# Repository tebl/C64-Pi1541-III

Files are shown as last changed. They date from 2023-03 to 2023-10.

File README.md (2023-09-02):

# C64 Pi1541-III
Well... if you're here, then that new and shiny SD2IEC for your Commodore 64 wasn't cycle-exact enough for you? Sure, there are great FPGA-based solutions available that can be purchased at a premium pricepoint. For the rest of us who are either on a tight budget - or - simply want something that they can build at home, then the excellent Pi1541-software written by Steve White may very well be the solution you've been looking for. With a Raspberry Pi 3 at its core, it is able to provide cycle-exact disk drive emulation with many improvements over the drive you had in your youth!

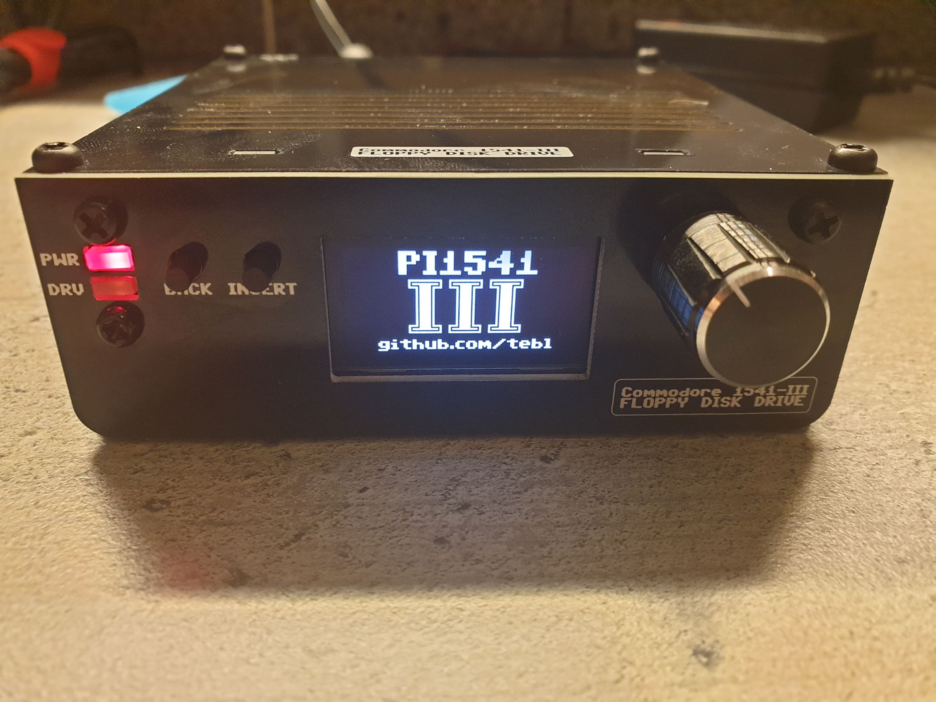
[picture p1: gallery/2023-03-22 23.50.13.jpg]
Pi1541-III


A Pi1541 can be constructed in many ways, but even though you can easily build one without the help of a PCB such as the ones provided by this project - I've found it a lot easier to make them work when you have a PCB available. I've released the design files for a more traditional Raspberry Pi-hat if you would rather build one of those, these can be found in my old repository at [C64-Pi1541-Module](https://github.com/tebl/C64-Pi1541-Module). A slightly different take on the device can also be found at [C64-Pi1541-II](https://github.com/tebl/C64-Pi1541-II) as it was made to resemble a slightly smaller stack of floppy disks.

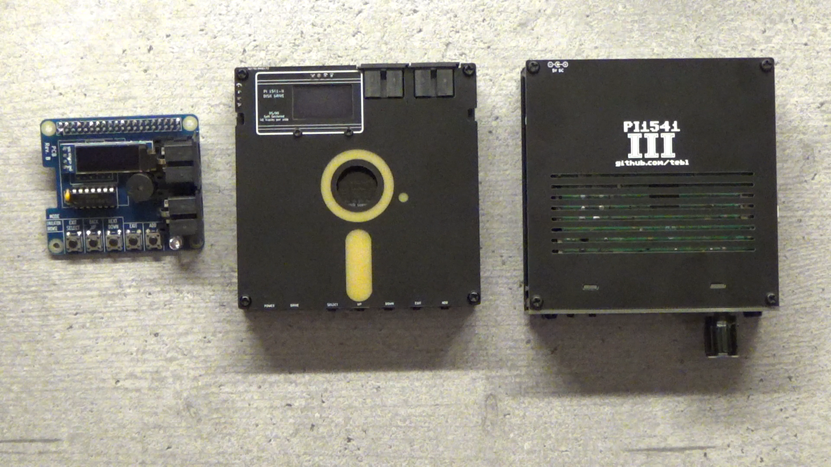
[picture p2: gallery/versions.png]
Three versions of Pi1541


With this third version I've instead attempted to make one that's more akin to a modern device, incorporating a 1.3" OLED on the front as being controlled via the use of a rotary encoder. While the design aesthetic makes it slightly harder to build than your standard Pi1541, I believe that it more than makes up for it.

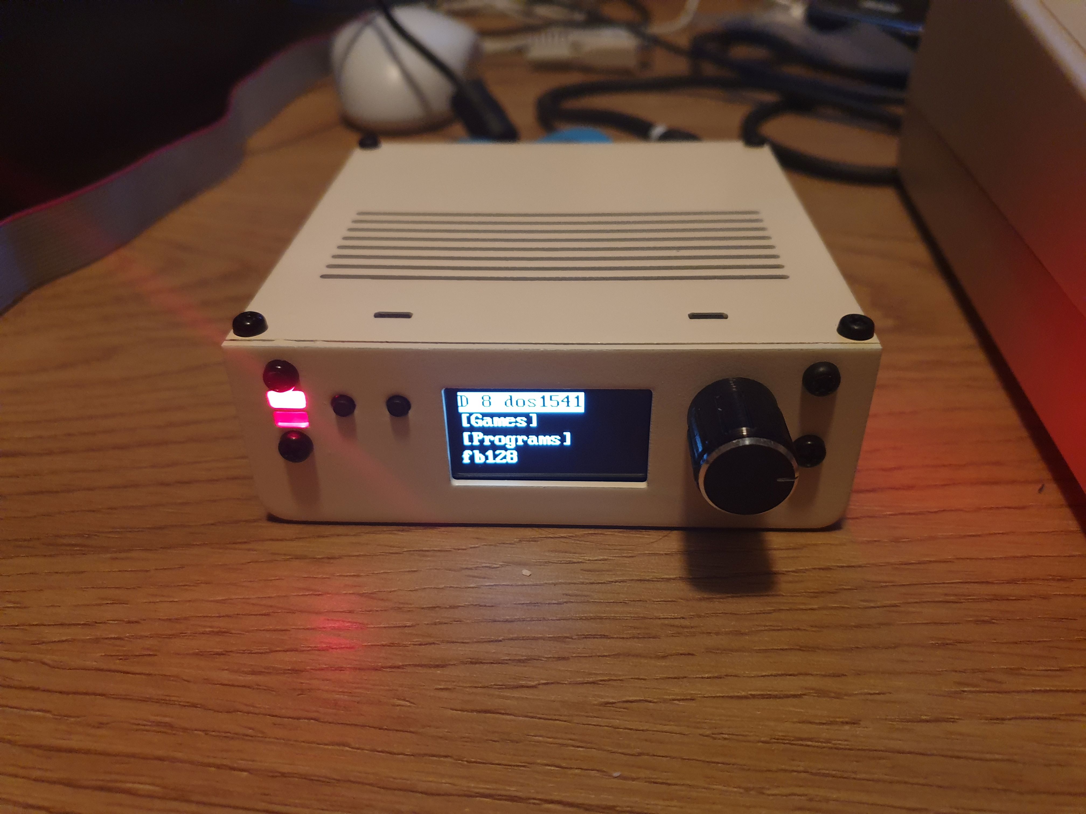
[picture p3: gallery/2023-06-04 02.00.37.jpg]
Pi1541-III (Painted)


- [1> Modules](#1-modules)
- [2> Documentation](#2-documentation)
  - [2.1> Resources](#21-resources)
- [3> Acknowledgements](#3-acknowledgements)

## 1> Modules
A complete Pi1541 requires no less than five PCBs in order to be built as pictured, for a somewhat simpler build you may skip the bottom faceplate though that also serves a purpose and it wouldn't entirely be complete without it. See below for a side view of how the device is put together, there is a top and bottom faceplate as well as another faceplate on the front. The PCB at the center will in the documentation be referred to as the *Pi1541-III Module* while the smaller one towards the front will be referred to as the *panel*.

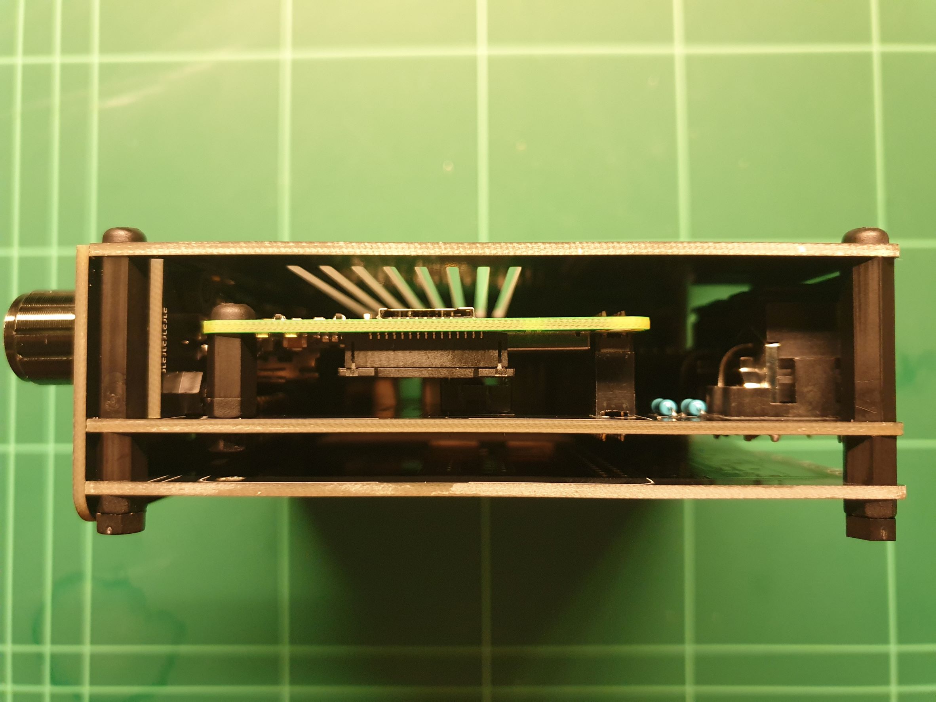
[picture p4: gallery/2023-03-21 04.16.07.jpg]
Pi1541-III side view


In order to keep things in an order that's mostly organized, I've had to separate out information such as the *BOM* that goes into the build for the modules they belong to - hopefully making things easier if I ever start doing alternate versions with other components. See further below for [documentation](#2-documentation) on how to assemble one, set it up as well as anything else that you might need to know.

| Module | Required | Description | Documentation | Order |
| --- | --- | --- | --- | --- |
| [C64 Pi1541-III Module](https://github.com/tebl/C64-Pi1541-III/tree/main/C64%20Pi1541-III%20Module) | Yes | Main module |  [BOM](https://github.com/tebl/C64-Pi1541-III/tree/main/C64%20Pi1541-III%20Module/README.md#3-bom) | [PCBWay](https://www.pcbway.com/project/shareproject/C64_Pi1541_III_Module_629bebca.html)
| [C64 Pi1541-III Module Panel](https://github.com/tebl/C64-Pi1541-III/tree/main/C64%20Pi1541-III%20Module%20Panel) | Yes | Adds a vertical surface for mounting switches and rotary encoder. |  [BOM](https://github.com/tebl/C64-Pi1541-III/tree/main/C64%20Pi1541-III%20Module%20Panel/README.md#3-bom) | [PCBWay](https://www.pcbway.com/project/shareproject/C64_Pi1541_III_Panel_39049bfb.html)
| [C64 Pi1541-III Faceplate (FB1)](https://github.com/tebl/C64-Pi1541-III/tree/main/faceplates/C64%20Pi1541-III%20Module%20FB1) | Yes | Top faceplate, provides mechanical support for front panel. | | [PCBWay](https://www.pcbway.com/project/shareproject/C64_Pi1541_III_Faceplate_FB1_d125443d.html)
| [C64 Pi1541-III Faceplate (FB2)](https://github.com/tebl/C64-Pi1541-III/tree/main/faceplates/C64%20Pi1541-III%20Module%20FB2) | Recommended | Bottom faceplate, adds a layer of security so that you don't accidentally short out the device on something placed under it. | | [PCBWay](https://www.pcbway.com/project/shareproject/C64_Pi1541_III_Faceplate_FB2_912f9cbb.html)
| [C64 Pi1541-III Faceplate (FP1)](https://github.com/tebl/C64-Pi1541-III/tree/main/faceplates/C64%20Pi1541-III%20Module%20FP1) | Recommended | Front faceplate, this is mainly here to make things look nice. | | [PCBWay](https://www.pcbway.com/project/shareproject/C64_Pi1541_III_Faceplate_FP1_228805ce.html)

# 2> Documentation
There are many things that need to be said in order to successfully put a working Pi1541 together, and while the information may seem pedantic and at that times simplified for veterans at building electronical devices - I'm just an amateur and so I try to include everything that would have been needed when I first started building things such as this.

If you've just come across this page and have been wondering exactly what components you need to order in order to build the Pi1541, then I suggest that you start on the [modules](#1-modules)-section - each of modules listed are PCBs that you will most likely want. In the same list there is a link to the BOM belonging to that specific module, you need to order the components for each of them.

This repository does not include Gerber-files, you either need to generate those from the KiCAD source files found in this repository - the easiest way to order them via [PCBWay](https://www.pcbway.com/project/shareproject/?tag=Pi1541-III). Note that for the faceplates specifically, you may want to pay a little bit extra to avoid having the order number printed on it - or specifically tell them to put it on the back.

For everything else, I can only hope that one of the following documents will provide you with the answers that you need:
- [Assembling one](https://github.com/tebl/C64-Pi1541-III/blob/main/documentation/assembling_one.md)
- [Setting it up](https://github.com/tebl/C64-Pi1541-III/blob/main/documentation/setting_it_up.md)
- [Troubleshooting](https://github.com/tebl/C64-Pi1541-III/blob/main/documentation/troubleshooting.md)

## 2.1> Resources
- [Pi1541 Homepage](https://cbm-pi1541.firebaseapp.com/)
- [fat32format](http://ridgecrop.co.uk/index.htm?guiformat.htm)
- [Shared PCBWay projects for Pi1541-III](https://www.pcbway.com/project/shareproject/?tag=Pi1541-III)

# 3> Acknowledgements
Everything comes from something, in particular when it comes to most of my electronics projects. I mainly build things I would like to own, often doing a respin to fit my own particular style and preferences with most of the hardest parts of the designs already provided by people more knowledgable than I.

The Pi1541-III would not exist if it were not for the work of Steve White, creator of the [Pi1541](https://cbm-pi1541.firebaseapp.com/)-software that makes this jumble of PCBs come alive!

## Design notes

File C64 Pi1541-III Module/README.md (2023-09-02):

# Pi1541-III Module
This is the main PCB and will hold most of the active components in the device, but note that it is designed to be used with [Pi1541-III Module Panel](https://github.com/tebl/C64-Pi1541-III/tree/main/C64%20Pi1541-III%20Module%20Panel) and has one listed in the [BOM](#3-bom). Note that the mentioned panel also has its own separate [BOM](https://github.com/tebl/C64-Pi1541-III/tree/main/C64%20Pi1541-III%20Module%20Panel/README.md#3-bom), so keep that in mind while ordering components.

- [1> Build instructions](#1-build-instructions)
- [2> Schematic](#2-schematic)
- [3> BOM](#3-bom)

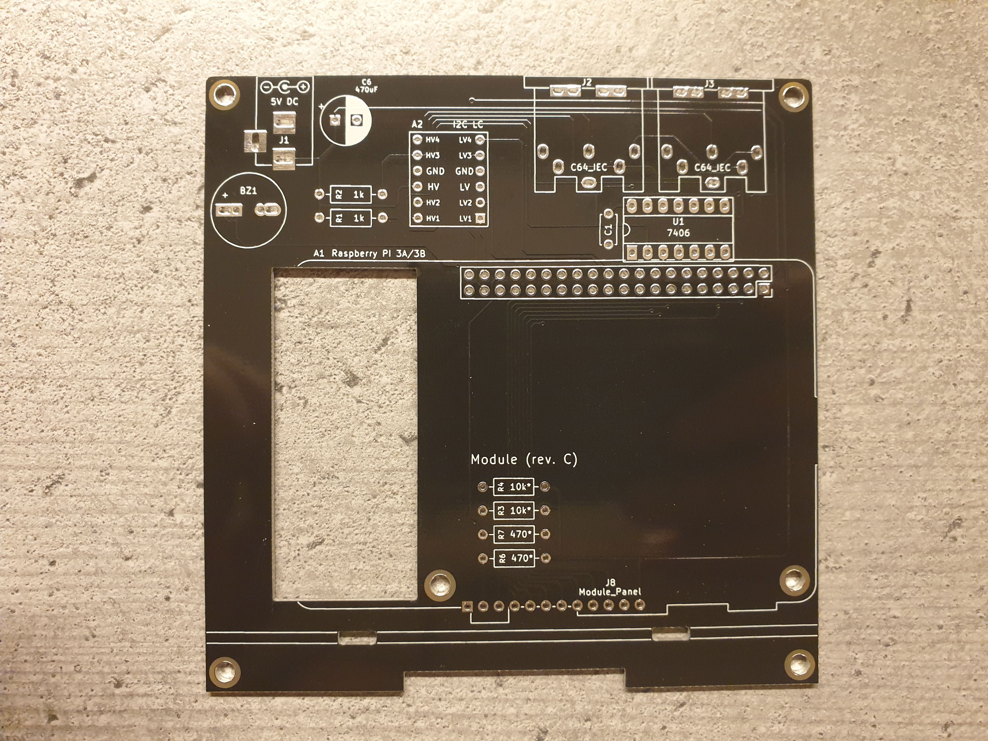
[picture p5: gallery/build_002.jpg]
Current PCB


# 1> Build instructions
Assembling this module is covered as part of the overall documentation, as linked below. Note that *BOM* is supplied per module, the one belonging to this module in particular is included as part of this document (click [here](#3-bom) to go there).

- [Assembling one](https://github.com/tebl/C64-Pi1541-III/blob/main/documentation/assembling_one.md)

# 2> Schematic
The supplied KiCad files should be sufficient as both a schematic and as a  starting point for ordering PCBs (basically you could just zip the contents of the export folder and upload that on a fabrication site), the schematic is also available in [PDF-format](https://github.com/tebl/C64-Pi1541-III/tree/main/documentation/schematic) and this is what you'll need to print and work your way through this things don't work as expected after assembly.

# 3> BOM
Most parts should be easy to get a hold of from your favourite local electronic component shop, but given that I don't have access to such shops where I live so everything was based on whatever I could get cheapest from eBay/AliExpress (free shipping, but plan on waiting 3-4 weeks for delivery). Components in parenthesis can be considered optional for features beyond the more basic functionality, but where's the fun in that? You deserve the complete package.

| Reference | Item | Count | Order  |
| --- | --- | ----- | --- |
| Module PCB | PCB specific to this project | 1 | [See modules](https://github.com/tebl/C64-Pi1541-III/blob/main/README.md#1-modules)
| Faceplate (FB1) PCB | Top faceplate | 1 | [See modules](https://github.com/tebl/C64-Pi1541-III/blob/main/README.md#1-modules)
| Faceplate (FB2) PCB | Bottom faceplate | (1)| [See modules](https://github.com/tebl/C64-Pi1541-III/blob/main/README.md#1-modules)
| A1 | 2x20 pin female header | 1 |
| | Raspberry Pi version 3B,3B+ or 3A+ | 1 |
| A2 *1 | 4ch I2C level converter module | 1 |
| BZ1 | Passive buzzer (pin spacing from 3.81 to 7mm will work) | (1) |
| C1 | 100nF ceramic capacitor (5mm) | 1 |
| C6 | 470uF electrolytic capacitor (8mm x 3.5mm) | 1 |
| J1 | 2.1mm x 5.5mm barrel plug | 1 |
| J2,J3 | Female S-terminal 6-pin DIN PCB |  1 (1)|
| J8 | [Pi1541-III Module Panel](https://github.com/tebl/C64-Pi1541-III/tree/main/C64%20Pi1541-III%20Module%20Panel) (completed unit) | 1 |
| R1,R2 | 1k Ohm resistor | 2 |
| R3,R4 | 10k Ohm resistor | 2 |
| R6,R7 *2 | 470 Ohm resistor | 2 |
| U1 *3 | 7406 (DIP-14) | 1 |
| Mounting *4 | Nylon M3 hex standoffs 6mm (M-F) | 4 |
| Mounting *4 | Nylon M3 hex standoffs 8mm (M-F) | 2 |
| Mounting *5 | Nylon M3 hex standoffs 12mm (M-F) | (4)|
| Mounting *4 | Nylon M3 hex standoffs 20mm (M-F) | 4 |
| Mounting *4 | Nylon M3x6mm nylon screws | 6 |
| Mounting *4 | Nylon M3x6mm nylon nuts | 12 |

1) There are multiple configurations of these being sold, this is usually sold with a blue PCB. When in doubt, compare the sale listing with the one shown in this [image](https://raw.githubusercontent.com/tebl/C64-Pi1541-III/main/gallery/build_006B.jpg).
2) This is the resistor for the LEDs mounted on [Pi1541-III Module Panel](https://github.com/tebl/C64-Pi1541-III/tree/main/C64%20Pi1541-III%20Module%20Panel), the value need to be sized according to the type of LED being used. This value is a somewhat safe choice cheaper coloured LEDs, for anything blue or especially marked as being *bright* - then you need to calculate a proper value for these.
3) There are unfortunately counterfeit 7406-chips being circulated, the ones I've had the most success with has been marked 7406PC though a handful of SN7406 have also been found working. See [troubleshooting](https://github.com/tebl/C64-Pi1541-III/blob/main/documentation/troubleshooting.md) for more information.
4) These are used in various places of the project, these are available in the form of kits usually advertised *M3 nylon standoff kit* which should contain most of what you'd need though you should check that they include them in sufficient quantity.
5) These are only needed when *NOT* installing bottom faceplate ([Pi1541-III Faceplate (FB2)](https://github.com/tebl/C64-Pi1541-III/tree/main/faceplates/C64%20Pi1541-III%20Module%20FB2))

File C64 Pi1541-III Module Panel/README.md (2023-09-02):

# Pi1541-III Module Panel
This PCB holds the components for the front panel, it was designed to mount on top of [Pi1541-III Module](https://github.com/tebl/C64-Pi1541-III/tree/main/C64%20Pi1541-III%20Module). This panel has its own BOM, so keep that in mind when ordering components - as you'll be needing parts listed for both of them to build a complete device.

- [1> Build instructions](#1-build-instructions)
- [2> Schematic](#2-schematic)
- [3> BOM](#3-bom)

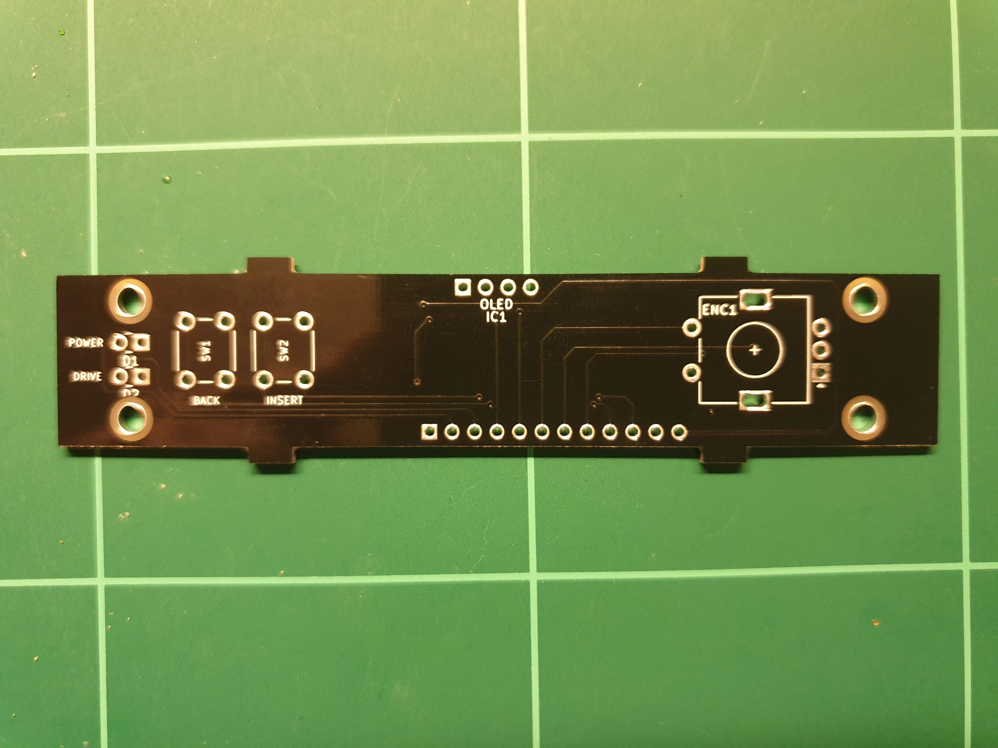
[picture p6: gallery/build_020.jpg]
Current PCB


# 1> Build instructions
Assembling this module is covered as part of the overall documentation, as linked below. Note that *BOM* is supplied per module, the one belonging to this module in particular is included as part of this document (click [here](#3-bom) to go there).
- [Assembling one](https://github.com/tebl/C64-Pi1541-III/blob/main/documentation/assembling_one.md)

# 2> Schematic
The supplied KiCad files should be sufficient as both a schematic and as a  starting point for ordering PCBs (basically you could just zip the contents of the export folder and upload that on a fabrication site), the schematic is also available in [PDF-format](https://github.com/tebl/C64-Pi1541-III/tree/main/documentation/schematic) and this is what you'll need to print and work your way through this things don't work as expected after assembly.

# 3> BOM
Most parts should be easy to get a hold of from your favourite local electronic component shop, but given that I don't have access to such shops where I live so everything was based on whatever I could get cheapest from eBay/AliExpress (free shipping, but plan on waiting 3-4 weeks for delivery). Components in parenthesis can be considered optional for features beyond the more basic functionality, but where's the fun in that? You deserve the complete package.

| Reference | Item | Count | Order  |
| --- | --- | ----- | --- |
| Module Panel PCB | PCB specific to this project | 1 | [See modules](https://github.com/tebl/C64-Pi1541-III/blob/main/README.md#1-modules)
| Faceplate (FP1) PCB | Front faceplate | (1)| [See modules](https://github.com/tebl/C64-Pi1541-III/blob/main/README.md#1-modules)
| IC1 *1 | SH1106 I2C OLED 128x64 (1.3") | 1 |
| ENC1 | EC11 rotary encoder, 20mm. Preferably plum handle. | 1 |
| | Suitable knob for rotary encoder, max 20mm in diameter. | (1)|
| D1,D2 | 2x5x7mm rectangular LED, suitably coloured. | 2 |
| J1 | 12-pin right-angle pin header | 1 |
| SW1,SW2 | 6x6mm momentary switch, 10.5mm or taller. | 2 |
| Mounting *2 | Nylon M3 hex standoffs 8mm (M-F) | 4 |
| Mounting *2 | Nylon M3x6mm nylon screws | 4 |
| Mounting *2 | Nylon M3x6mm nylon nuts | 4 |

1) Many of these will be listed for sale as 1.3" ssd1306-based OLED displays, but they actually have the slightly different sh1106-controller. Something to keep in mind when ordering.
2) These are used in various places of the project, these are available in the form of kits usually advertised *M3 nylon standoff kit* which should contain most of what you'd need though you should check that they include them in sufficient quantity.

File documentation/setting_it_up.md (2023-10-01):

# 1> Setting it up
This part of the documentation takes care of setting up your Pi1541-III, taking care of everything needed to enjoy using it after the hardware has previously been [assembled](https://github.com/tebl/C64-Pi1541-III/blob/main/documentation/assembling_one.md). While most of this information would be relevant to any build of a pi1541, this guide will cover the relevant differences for the Pi1541-III in particular - type of display, use of rotary encoder, that kind of *thing*.

- 1> Setting it up
- [2> Video](#2-video)
- [3> Written instructions](#3-written-instructions)
  - [3.1> Preparing SD-card](#31-preparing-sd-card)
  - [3.2> Copying necessary files](#32-copying-necessary-files)
  - [3.3> Edit configuration](#33-edit-configuration)
  - [3.4> Testing it out](#34-testing-it-out)

## 2> Video
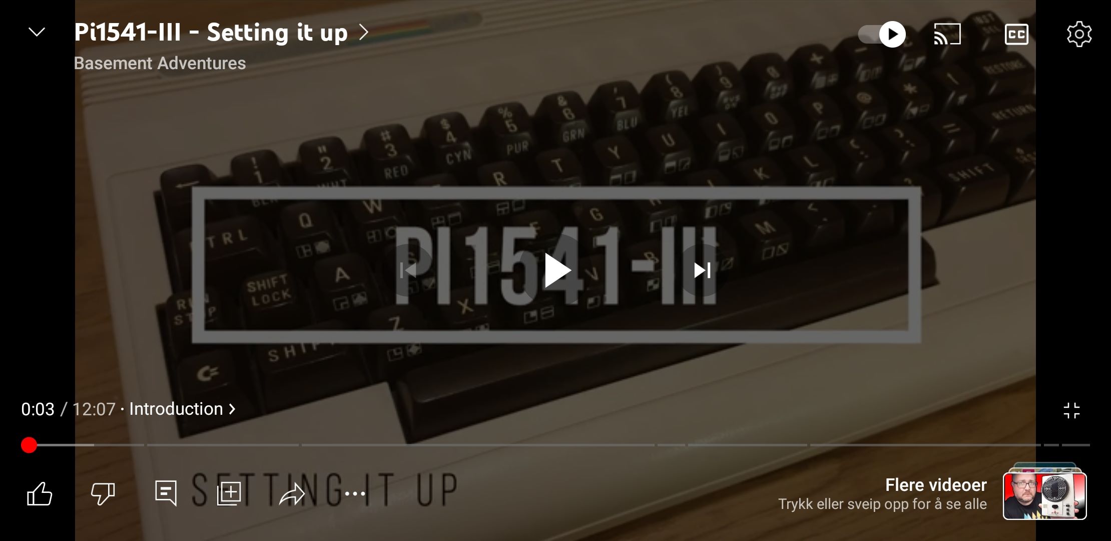
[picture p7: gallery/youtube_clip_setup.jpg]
YouTube image (https://youtu.be/a_sJkwbnSls)


## 3> Written instructions
As a video for this exists, I'll try to keep this brief by mainly attempt to supplement the contents of it - if you hate having to pause a video to read a piece of text, then this is the section you wanted. The following sections have been provided, feel free to skip ahead if you feel confident in your own abilities - and - promise to return when you find out that things did not work as expected (or at all).

- [3.1> Preparing SD-card](#31-preparing-sd-card)
- [3.2> Copying necessary files](#32-copying-necessary-files)
- [3.3> Edit configuration](#33-edit-configuration)
- [3.4> Testing it out](#34-testing-it-out)
  
### 3.1> Preparing SD-card
In order to prepare an SD-card, you will first need to have an SD-card and an SD-card reader. The speed isn't all that much of an issue, a *reasonably* priced slower cards will more than likely work - you'll simply end up waiting longer when adding your entire collection of disk files to it. One thing that is **important**, is that you bought a "*reasonably* priced card", if it seemed like too much of a good deal when ordering it online - then it's practically guaranteed to have been produced with a non-existing capacity. Throw them away and get a refund, any data added beyond a certain limit will simply overwrite previous data and you'll have a cycle of corruption that will in no way function. 

The card that you ended up purchasing from a good local electronics vendor (with or without extra steps due to fake products bought), won't have a file system that a Raspberry Pi can boot from - most cards from 16GB and upwards will have been formatted for you with the *exFAT* file system instead. We need it to have *FAT32*, something that most operating systems by anyone other than Microsoft should handle fine (just make sure that you format the correct drive).

If you were to use any version of Microsoft Windows, then all hope is definitely not lost - we just require some third-party tools to do that. There are a few good ones out there, but there's a LOT of spyware, bloatware and straight up ransomware masquerading as such tools - so use one that you're familiar with and trust. The one I tend to use is [fat32format](http://ridgecrop.co.uk/index.htm?fat32format.htm) - it might look like something from a couple of centuries ago, but so is the one that came with MS Windows so here we are then. Make sure that you format the correct drive.

### 3.2> Copying necessary files
From the pi1541 homepage at [https://cbm-pi1541.firebaseapp.com/](https://cbm-pi1541.firebaseapp.com/), download the latest binaries for setting up a new SD-card - open up the archive and copy the **contents** of the Pi1541 directory directly to the root of your SD-card.

Download the [Raspberry Pi Foundation](https://github.com/raspberrypi/firmware/archive/1.20180919.zip) archive, opening it up you need to open the first and only folder on it. Within the subsequent subfolder, named **boot**, you'll need to copy the following files to the root of your SD-card:
- bootcode.bin
- fixup.dat
- start.elf

The final piece are the ROM-files from an actual Commodore 1541 disk drive, but we don't need to look for a chip extractor just yet - the files are thankfully already included as part of the [VICE](http://vice-emu.sourceforge.net/windows.html) emulator. Download the first listed Zip-file, it doesn't matter if you're not going to be able to run it on your non-Microsoft operating system - as mentioned, we only needed a few files. Opening up the archive, head into the first and only folder - copy the following files to the root of your SD-card.
- DRIVES\dos1541
- DRIVES\dos1571
- DRIVES\dos1581
- C64\chargen

In order to verify that the Pi1541-III has been built correctly, it is recommended that you also download a copy of [Ghosts'n Goblins Arcade](https://www.n0stalgia.org/common/pages/releases.php?op=showrelease&id=329). Open up the archive and copy the d64-file to the 1541-folder on your SD-card.

### 3.3> Edit configuration
The configuration for the Pi1541 software can be changed by editing *options.txt*, a file that should previously have been copied over to your SD-card. We will however need to make some changes to it, the Pi1541-III has been dedisgned to be used with very specific components and we need to set some options in order to make things work. I won't go into a huge amount of details, but suffice it to say you should use the default configuration and make the changes listed below to it.

The first change is to tell it that we've built it up as an option B device, all of the Pi1541-variants designed by me have been built in this way. We therefore need to uncomment this line, as such:
```
// If you are using the split line hardware option (ie Option B) then you need to specify this option
splitIECLines = 1
```
Given that the Pi1541-III was designed for use with a physical display, we won't be needing some of the HDMI functionality and can deactivate those (ideally making the device work less, generating less heat, in theory at least). This is done by changing the value to a zero as such:
```
// This option displays the IEC bus activity on the bottom of the Pi's screen
GraphIEC = 0
```
The buzzer on the device can be enabled, this generates some audiotory feedback to let you know that the device is currently doing something. It's not designed to make any kind of realistic noises, but at least you know that it is doing something instead of just hanging on a dodgy disk image.
```
SoundOnGPIO = 1
SoundOnGPIODuration = 1000 // Length of buzz in micro seconds
SoundOnGPIOFreq = 1200 // Frequency of buzz in Hz
```
The display type needs to be set correctly, anything else will simply result in garbage or nothing at all showing up on the screen. For the Pi1541-III specifically I designed it with the 1.3" OLED modules in mind, these are often sold as ssd1306 compatible displays though they are obviously not - for that reason we need to specify the actual display chip found on them (*sh1106*)
```
// If you are using a LCD screen then specify it here
//LCDName = ssd1306_128x64
//LCDName = ssd1306_128x32
LCDName = sh1106_128x64
```
Some custom boot images have been provided as part of the Pi1541-III project, as well as needed tools in order to create them. These can be found within this repository at [/software/xbm_convert](https://github.com/tebl/C64-Pi1541-III/tree/main/software/xbm_convert), the "raw"-files must be copied to the root of your SD-card. These are optional and I'm mainly including this information as I wasn't able to find it elsewhere, the last line is uncommented and changed to point to one of the new logos.
```
// change startup logo on oled - 1541ii or 1541classic
//LcdLogoName = 1541ii
//LcdLogoName = 1541classic
LcdLogoName = logo_pi1541.raw
```
The final change needed is to set it up to read the rotary encoder that we'll be using, this is replaces the previous way of navigating menus via switches:
```
//ROTARY:
//
//    Please see dmRotary.h for full implementation details.
//
RotaryEncoderEnable = 1
```

With all of that done, make sure to save your changes and safely eject your SD-card.

### 3.4> Testing it out
Plug in the SD-card, then let's pause for a bit to talk about safe power supply choices - in general the extremely cheap options will be cheap **because** they omit all of the features that would normally keep them from burning your house down! As the plug is quite common and just about anything takes 5v these days, consider a proper PSU an investment that you'll be using for all of your other projects as well.

So where do you get proper ones then? Usually an electronics vendor that is local to you, if you are potentially able to punch them in the face - then they won't sell you dangerous stuff. What you'll be looking for should have a standard "barrel" plug on it, but if only to give you something more specific to look for - the one I'm using is a MeanWell GST25B05-P1J (you may need a different model depending on where you live in the world).

With the SD-card plugged in and power applied to it (without connecting it to your C64), then it should start up and allow you to browse the menus using the rotary encoder. If nothing happens or it doesn't seem to work right, please retrace your steps to make sure that the configuration is correct - you can also check out the [troubleshooting](https://github.com/tebl/C64-Pi1541-III/blob/main/documentation/troubleshooting.md) section.

Hooking it up to the C64 you may notice that upon starting up, the display may go blank once the boot logo has been shown - this is the default behaviour when a C64 is connected, but have not been powered on. Turning on the C64 you should be able to browse the menu again, navigate into the 1541 folder and look for that copy of [Ghosts'n Goblins Arcade](https://www.n0stalgia.org/common/pages/releases.php?op=showrelease&id=329) that you copied over earlier, click the rotary encoder to have the Pi1541 start emulating a disk drive with that specific disk inserted.

First ensure that you are able to list the disk contents:
```
LOAD "$",8
LIST
```
If that immediately failed with an error without seeing the Pi1541 activity lights lit up, I would usually suspect a quality issue with the i2c level converter module (in my experience, 2 out of 10 are usually faulty). To rule out the C64, either try connecting a real Commodore 1541 disk drive or alternatively a different C64.

If that looked like it worked, then let's just continue along our merry way and start loading up that game:
```
LOAD "*",8,1
RUN
```
With a fully working Pi1541-III you should be able to load the game all the way via an initially loading menu in between, in particular you should look for corruptions on the image that loads at first (usually pointing to a fake 7406 chip). If it hangs during loading, you may have some other issue -usually solved by using a suitable quality PSU for the Raspberry Pi. Check out [troubleshooting](https://github.com/tebl/C64-Pi1541-III/blob/main/documentation/troubleshooting.md) if you're still stuck at this point.

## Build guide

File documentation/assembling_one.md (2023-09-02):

# 1> Assembling one
Assembling a Pi1541-III from scratch can seem a bit intimidating at first, or not intimidating enough depending on how you look at it. There are quite a lot of things that need to be put together in ways that don't have a huge tolerance for error, that's not to say that it is hard - all that's required is simply to take your time with it. It's more akin to a 3d-puzzle than a standard flat piece of PCB.

- 1> Assembling one
- [2> Video](#2-video)
- [3> Written instructions](#3-written-instructions)

## 2> Video
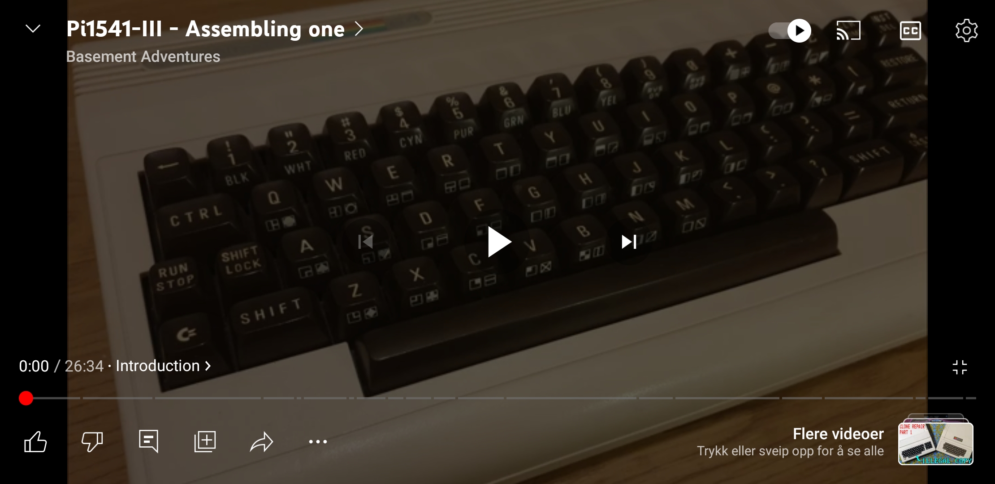
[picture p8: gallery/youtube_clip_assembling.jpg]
YouTube image (https://youtu.be/azvZLPPi7Ts)


## 3> Written instructions
Unfortunately the written instructions don't seem to exist yet.

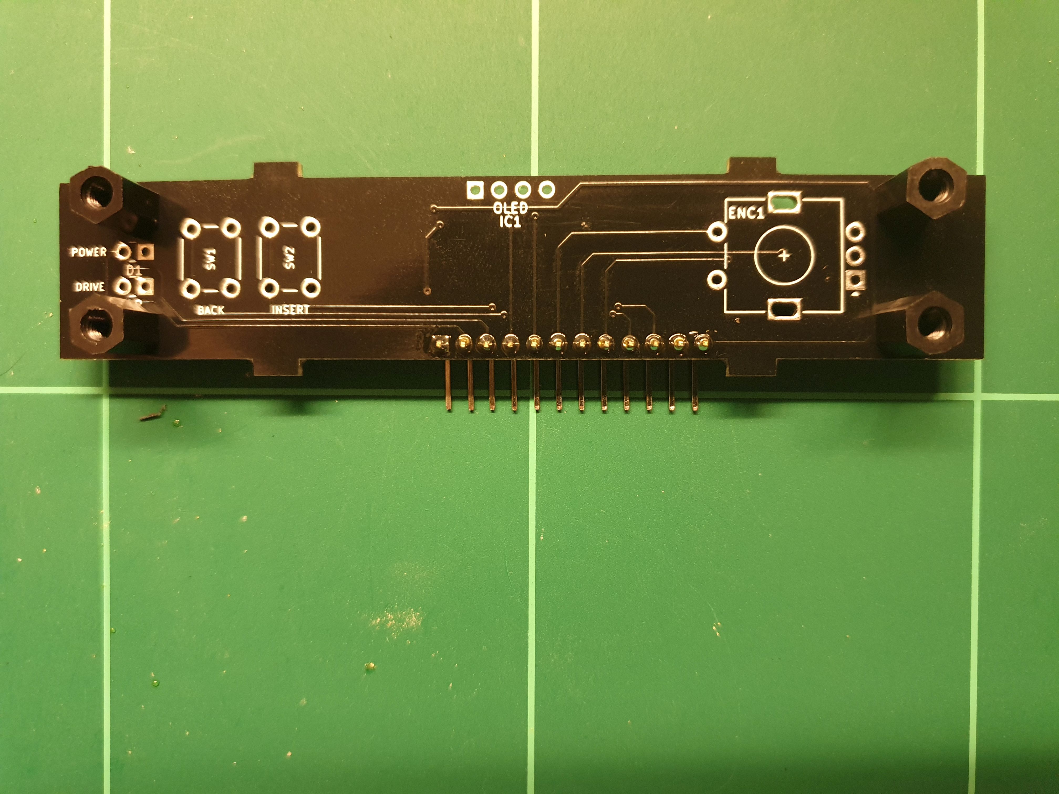
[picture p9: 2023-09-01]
gallery/build_024.jpg

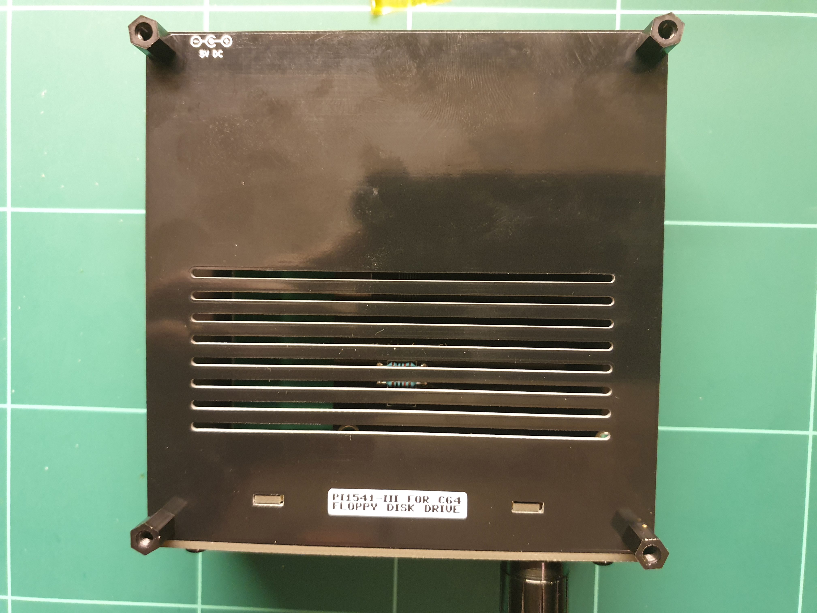
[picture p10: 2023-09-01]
gallery/build_032.jpg

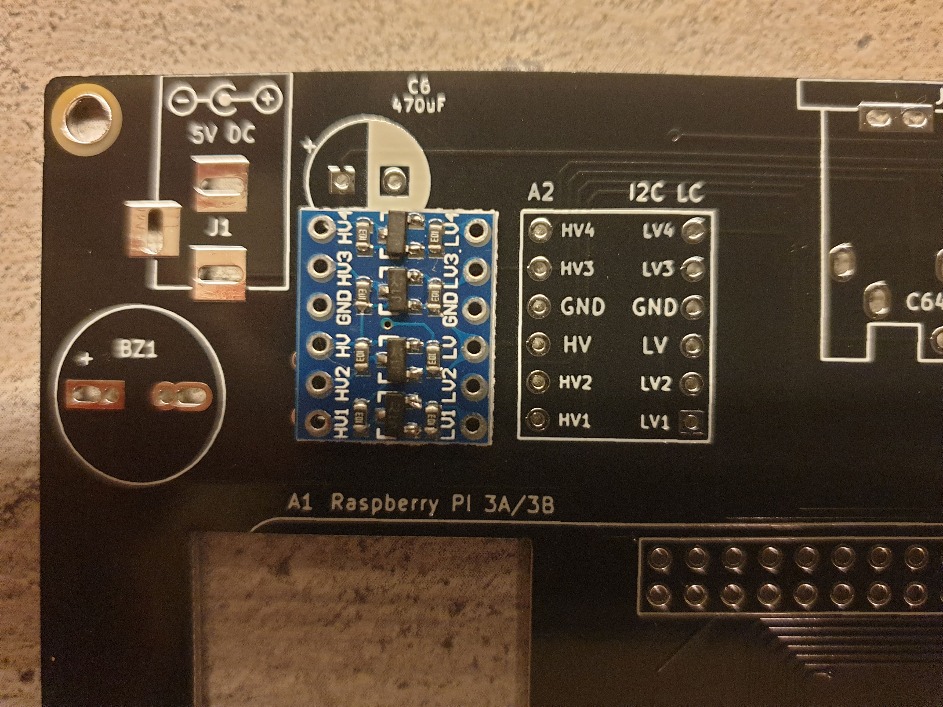
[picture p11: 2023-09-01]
gallery/build_006B.jpg

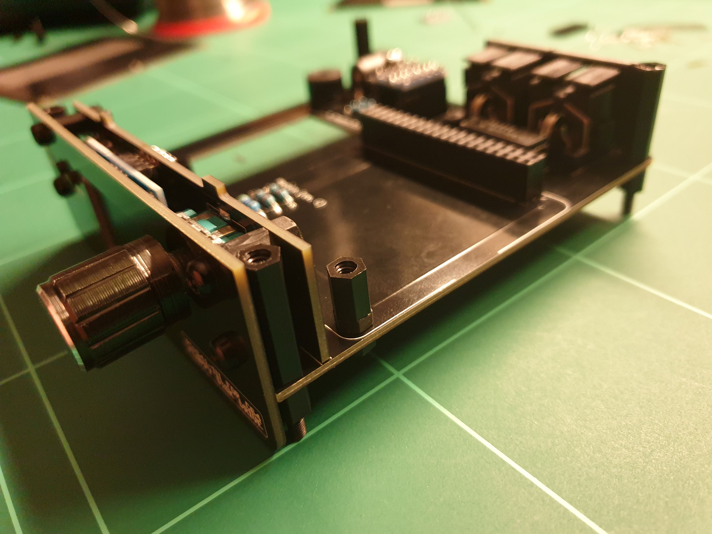
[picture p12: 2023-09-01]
gallery/build_030.jpg

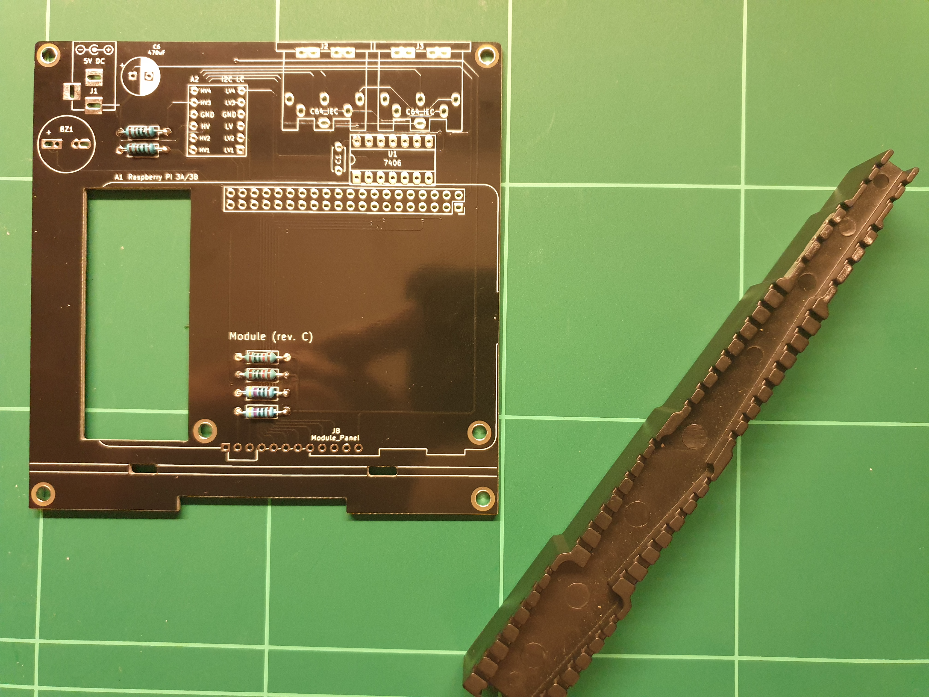
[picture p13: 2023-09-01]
gallery/build_003.jpg

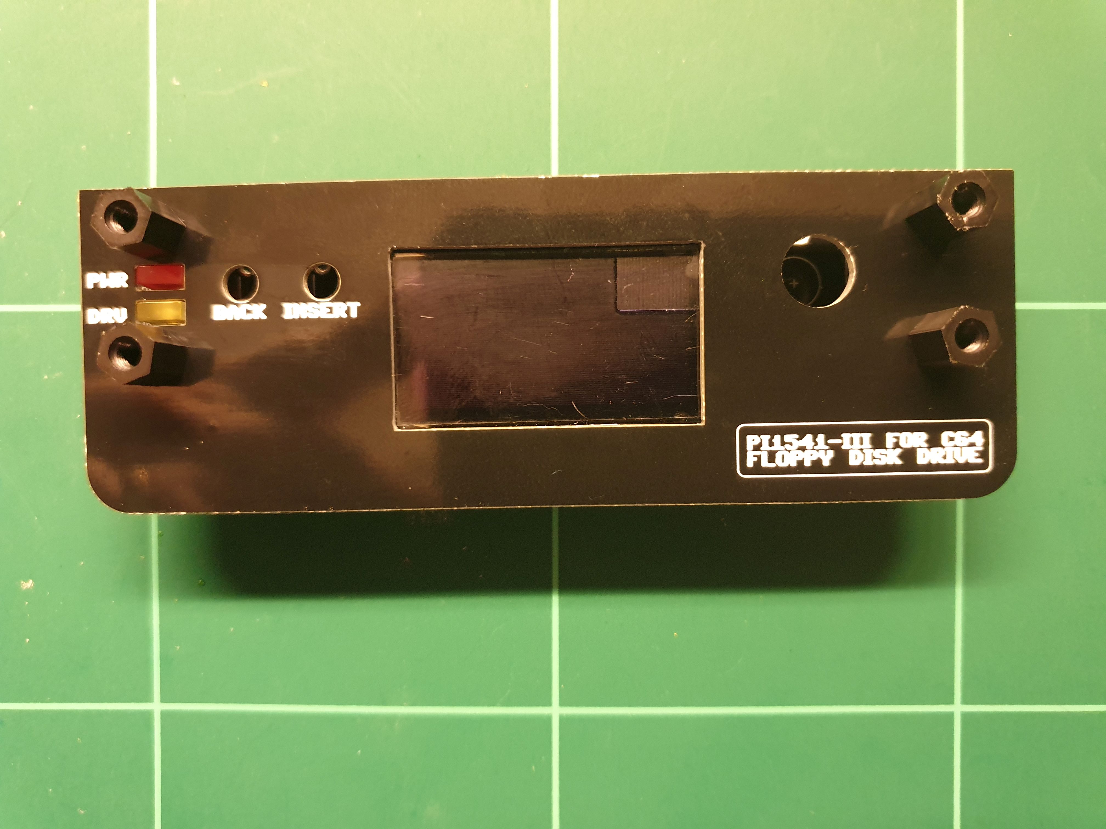
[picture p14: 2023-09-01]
gallery/build_026.jpg

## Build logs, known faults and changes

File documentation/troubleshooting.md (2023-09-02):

# 1> Troubleshooting
Well... if you're here, then something must have gone wrong. Damn... 

Do not despair, take a deep breath and start working through the basics. A frequent problem that has been posted on the site for the Pi1541 firmware itself, is that under-powered power supplies will often cause problems for you. While some may consider it a design weakness, I've found that when it comes to powering a Raspberry Pi 3, or later versions for that matter, there are no easy solutions beyond plugging a PSU straight into it - and so it takes a PSU providing 5V DC via a barrel plug. In todays market there are many power supplies that are simply unbelievably cheap, the last one I bought started gradually toasting whatever was plugged into it after a year or so. One affordable, yet trustworthy PSU is the GST25B05-P1J produced by Mean Well (this has a EU plug on it, for other regions you may need a slightly different model).

With the power issues either solved or ruled out, does the display work? If it is completely dark, take the Pi out of the Pi1541-III and allow it to start up with HDMI connected to a modern monitor. If you either get a black screen or a rainbow-coloured one, please check your SD-card - can you tell if there is a difference when starting up with or without a card inserted? The most likely cause of your problems is that the card has been formatted using the exFAT file system from the factory, a Raspberry Pi is currently unable to boot from any other file system than FAT32. If that is the case you need to format the card to FAT32, something that isn't straight forward on newer versions of MS Windows - one third-party tool such as [fat32format](http://ridgecrop.co.uk/index.htm?guiformat.htm) can format the card for you (just don't accidentally format a different drive by accident).

Put it back in again, still nothing on the OLED-display despite having checked that the configuration is correct? Double-check your previous notes so that you've soldered JP3/JP4 on the [Pi1541-III Module Panel](https://github.com/tebl/C64-Pi1541-III/tree/main/C64%20Pi1541-III%20Module%20Panel) according to the actual pin order on your OLED - if you've forgotten to do so, then do it now and try again. Did you do it the wrong way around and have already attempted to power up the thing, you know that it is probably dead now? In which case, you should order a new display though you may have gotten lucky. If you observe graphical glitches, you may have configured the display as a *ssd1306*-based display and although the sales listing usually say *ssd1306* - every 1.3" display I've encountered are actually based on the *sh1106* and need to be configured as such.

You've gotten this far, then that's super-awesome! Hopefully you can select a d64 file from your SD-card, move up/down to the file and click select to start emulating a drive with that disk inserted. Try to load up the directory listing from your Commodore 64:
```
LOAD "$",8
```
If it fails instantly with a message saying "DEVICE NOT PRESENT", your 7406 might not be working as it should or possibly not at all (ensure your C64 actually works with the same cable and with a real disk drive first, if possible). Try a different chip and hope that it works.

If you get a different error or quite possibly the Commodore 64 just hangs there without doing anything, a good bet is that the I2C level converter is crappy - I've had around 20% DOA on those things, so it is not unlikely. My best recommendation is to use a multimeter and measure the resistance across various points, more than likely you can spot the one where nothing is connected by comparing between them (they usually come in packs of 5 or 10 so you should have spares).

Something else that may come up is that some 7406 chips have been distributed with known issues, these can cause slightly less dramatic faults and simply cause data to load in with errors. For this reason the creator of the Pi1541-software, also recommends that you test by loading in *Ghost'n Goblins Arcade* to check that the chip is performing adequately - in particular the loading screen will have graphical issues. No Pi1541-III is therefore never considered adequately tested before it can reliably load this particular disk image. Your mileage may vary, but the chips that I've had the most luck with have been specifically marked *7406PC* and can be usually found for sale at a higher price than the cheap ones.

Finally, if the computer just says READY then that is not an error - you just need to brush up on your BASIC commands. That's all I have, please feel free to join the C64 Facebook group if more assistance is needed (there's usually helpful people hanging around there).

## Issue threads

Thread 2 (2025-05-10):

Feature Request - Integrate a microSD to SD reader

kmasaryk, 2025-05-10:
Dealing with the tiny microSD cards is not fun and I find myself doing it frequently to add software to the card. I would love it if this project could incorporate a microSD to SD adapter which would allow using an SD card at the front of the device. I think it would look pretty neat too since it would more resemble a "real" drive where you insert a disk at the front.

[Here's an example](https://www.amazon.com/dp/B0D7YZ5PG3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) of a converter with a length of cable between each end I found at Amazon.

I could hack it together myself but I'm sure you could design something which looks much nicer!

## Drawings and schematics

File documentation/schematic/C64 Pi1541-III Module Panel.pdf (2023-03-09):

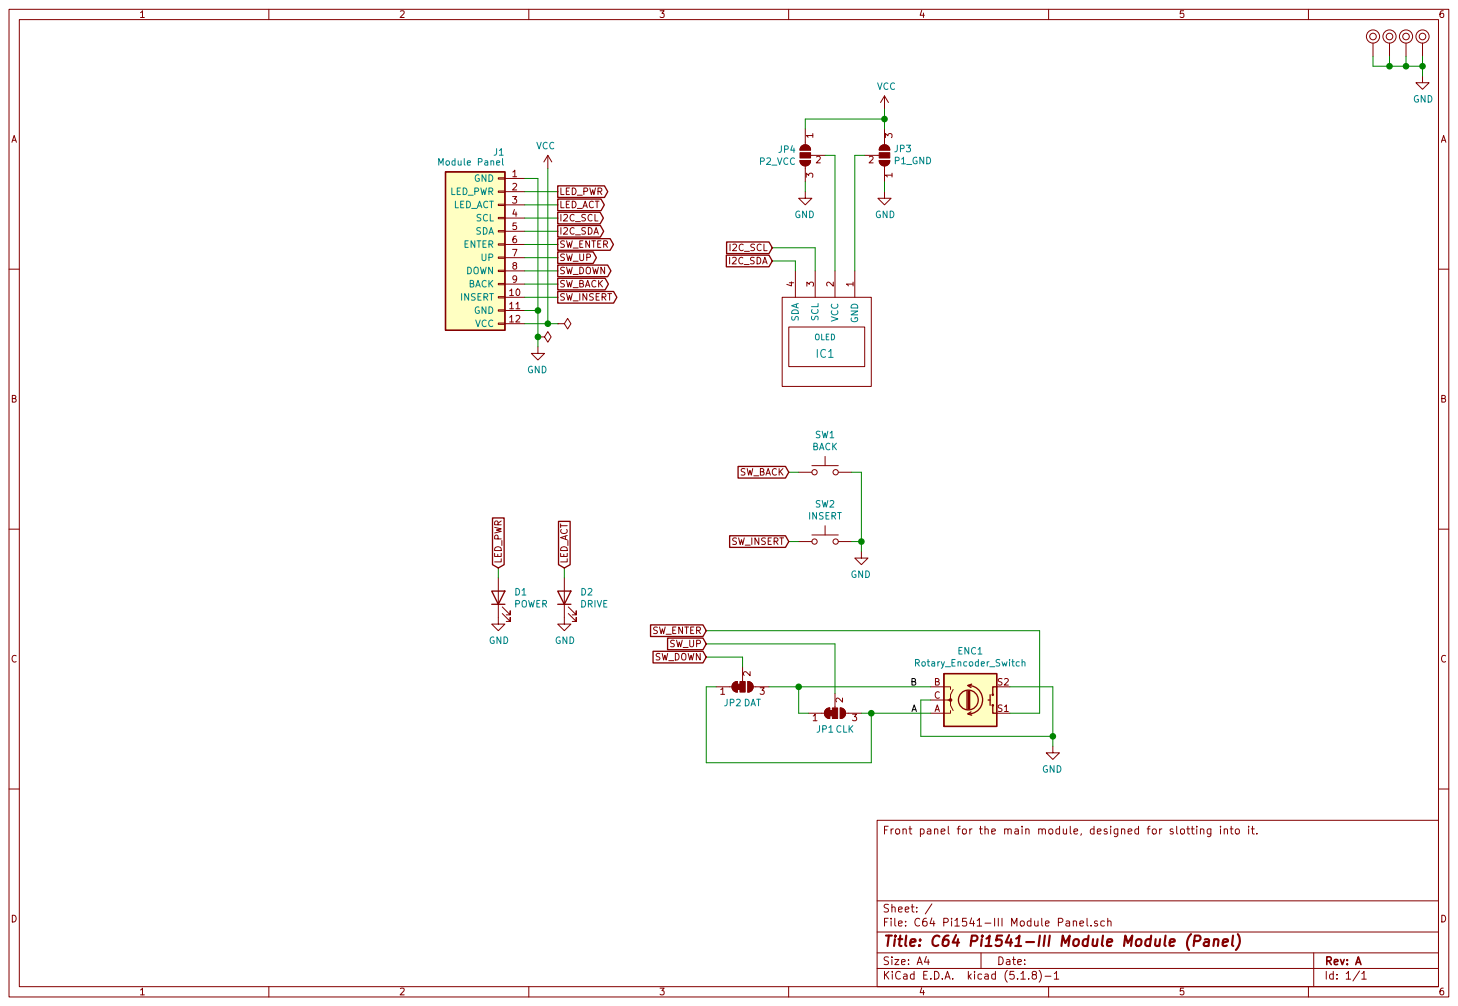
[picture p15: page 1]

Id: 1/1 Title: C64 Pi1541-III Module Module (Panel) File: C64 Pi1541-III Module Panel.sch Sheet: / Front panel for the main module, designed for slotting into it.

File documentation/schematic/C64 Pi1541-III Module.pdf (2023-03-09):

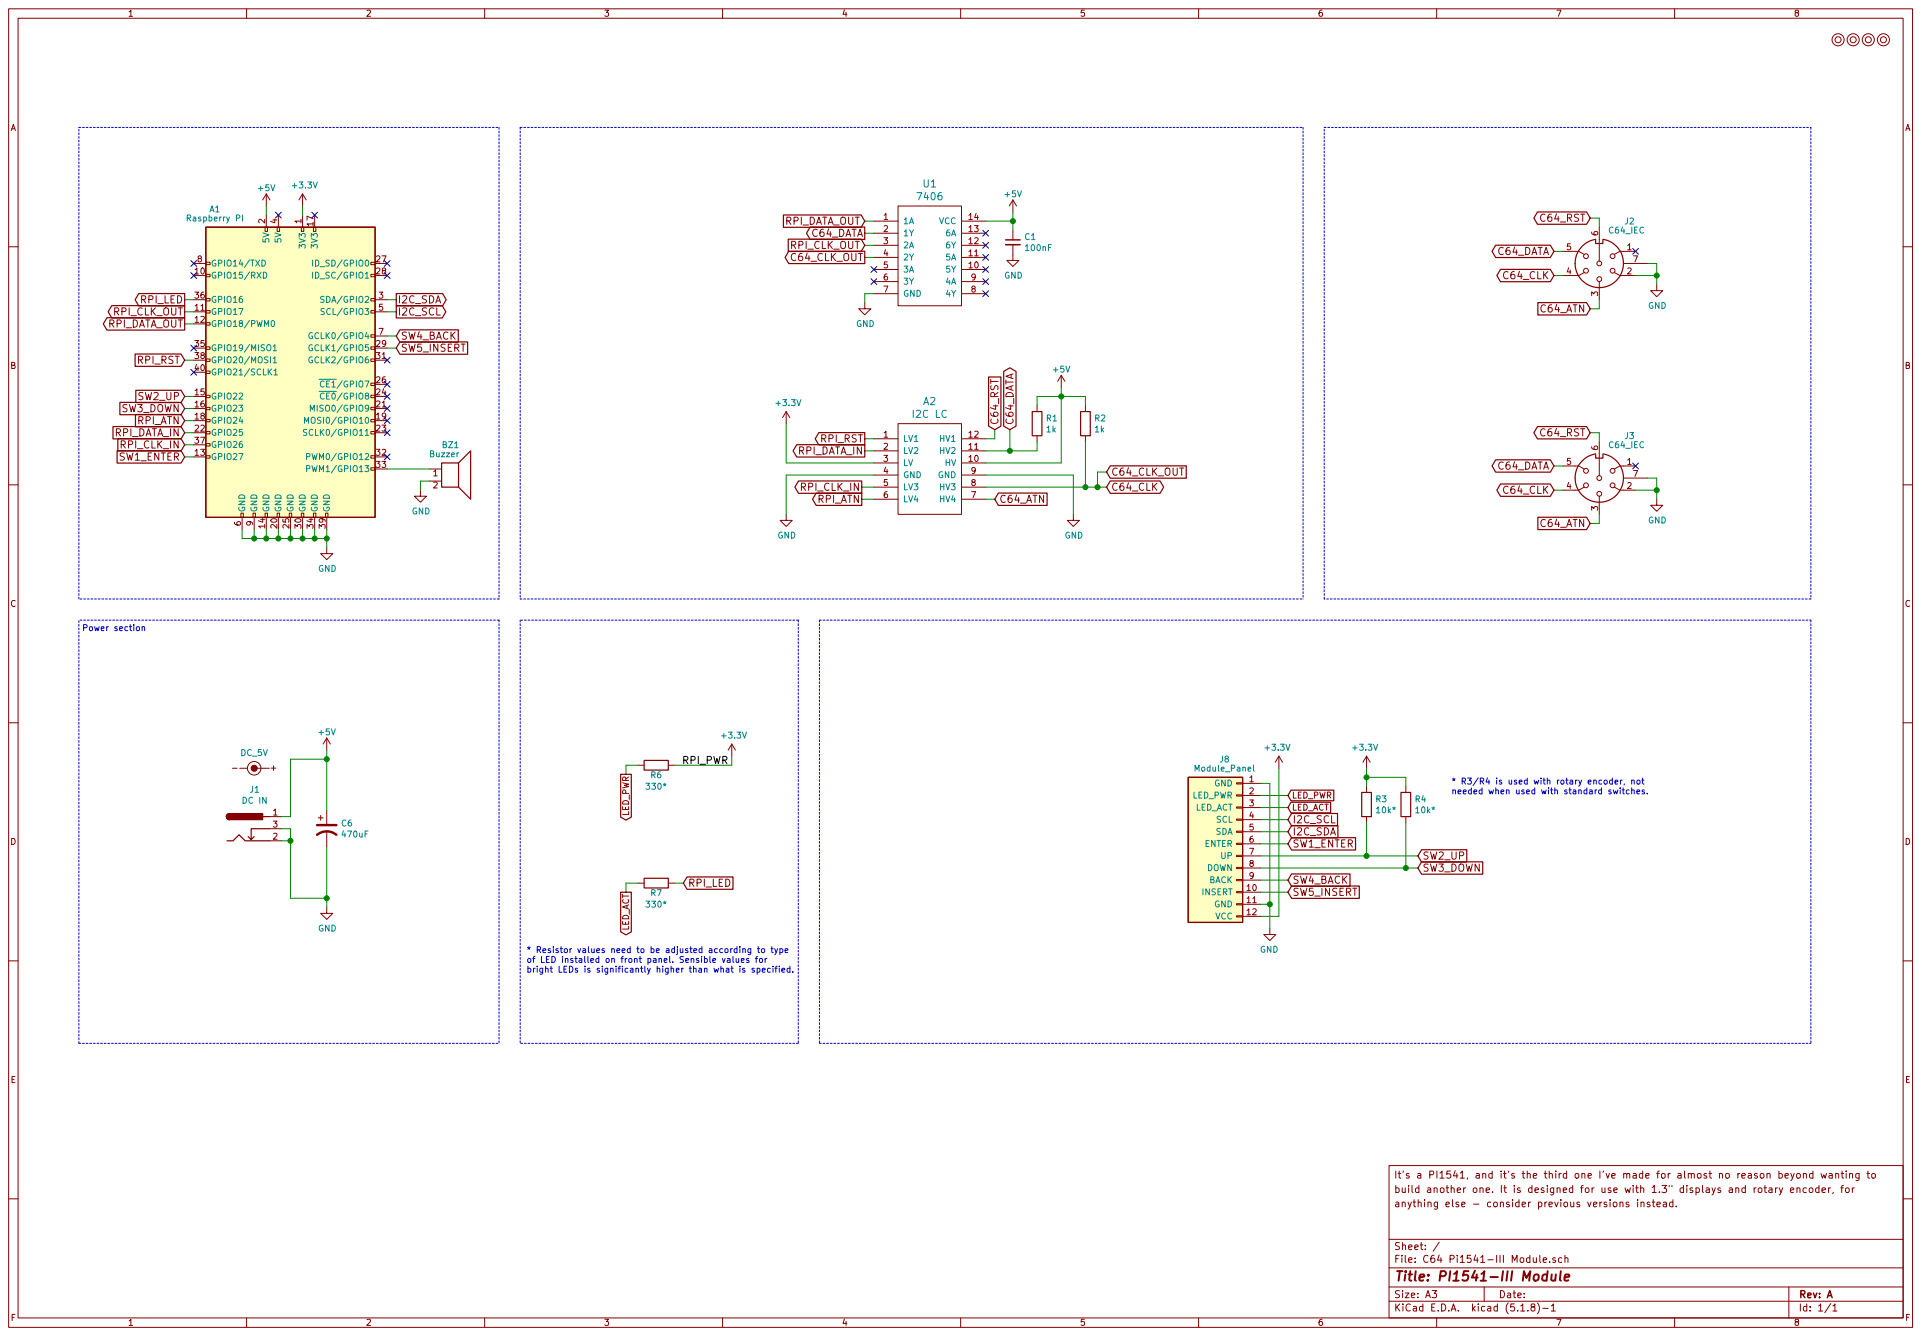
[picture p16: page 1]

bright LEDs is significantly higher than what is specified. Power section

* R3/R4 is used with rotary encoder, not needed when used with standard switches. * Resistor values need to be adjusted according to type

of LED installed on front panel. Sensible values for

It's a PI1541, and it's the third one I've made for almost no reason beyond wanting to
build another one. It is designed for use with 1.3" displays and rotary encoder, for
File: C64 Pi1541-III Module.sch Sheet: / anything else - consider previous versions instead.

Id: 1/1 Title: PI1541-III Module

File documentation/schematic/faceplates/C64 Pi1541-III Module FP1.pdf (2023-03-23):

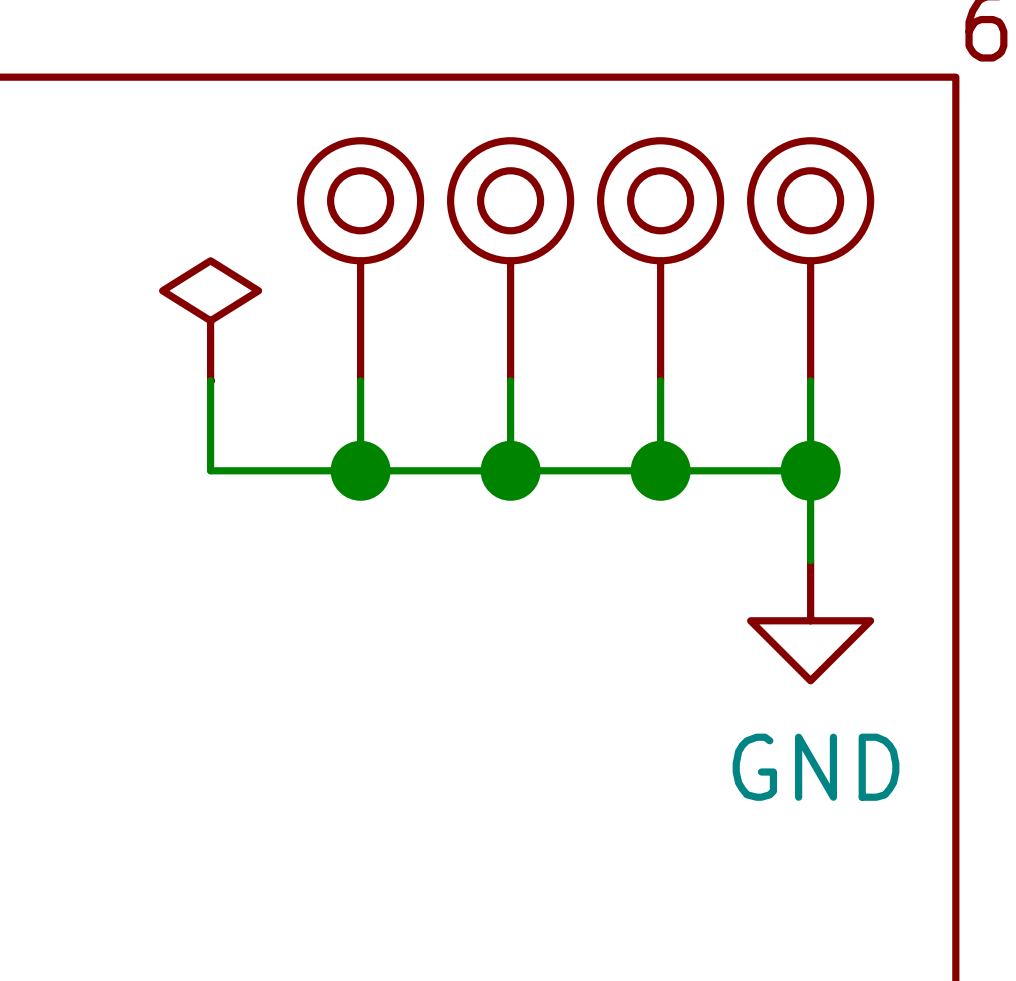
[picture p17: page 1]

Module front panel, mounts on the panel itself.
Id: 1/1 Title: Module Panel (Faceplate FP1) File: C64 Pi1541-III Module FP1.sch Sheet: / Use with 1.3" display.

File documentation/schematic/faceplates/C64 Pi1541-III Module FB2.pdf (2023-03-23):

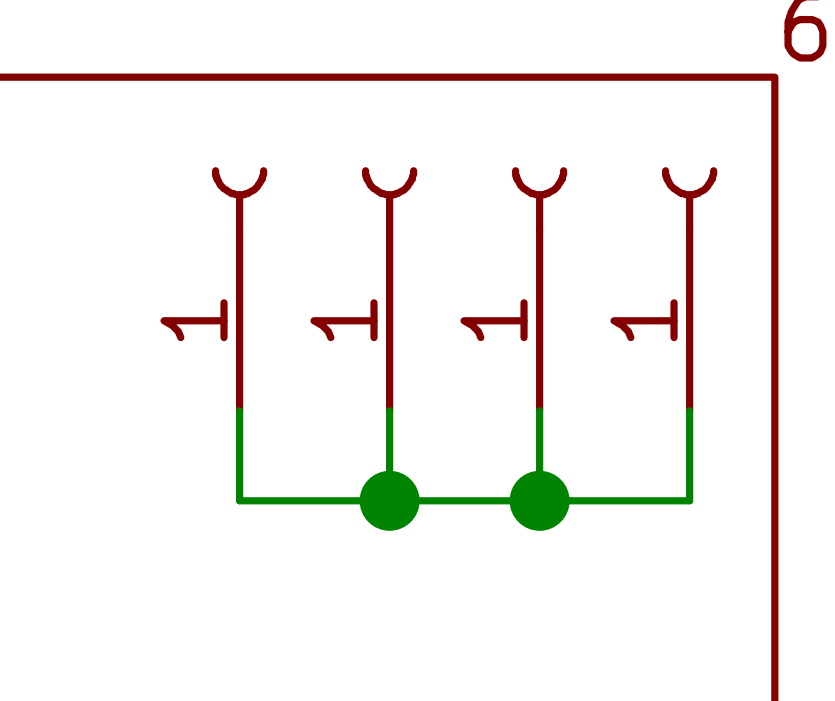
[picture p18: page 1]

Id: 1/1 Title: Pi1541-III Faceplate (FB2) File: C64 Pi1541-III Module FB2.sch Sheet: / This is a clean version of the bottom faceplate.

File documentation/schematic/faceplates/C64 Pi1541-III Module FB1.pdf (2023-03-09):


Id: 1/1 Title: Pi1541-III Faceplate (FB1) File: C64 Pi1541-III Module FB1.sch Sheet: / This is a clean version of the top faceplate.

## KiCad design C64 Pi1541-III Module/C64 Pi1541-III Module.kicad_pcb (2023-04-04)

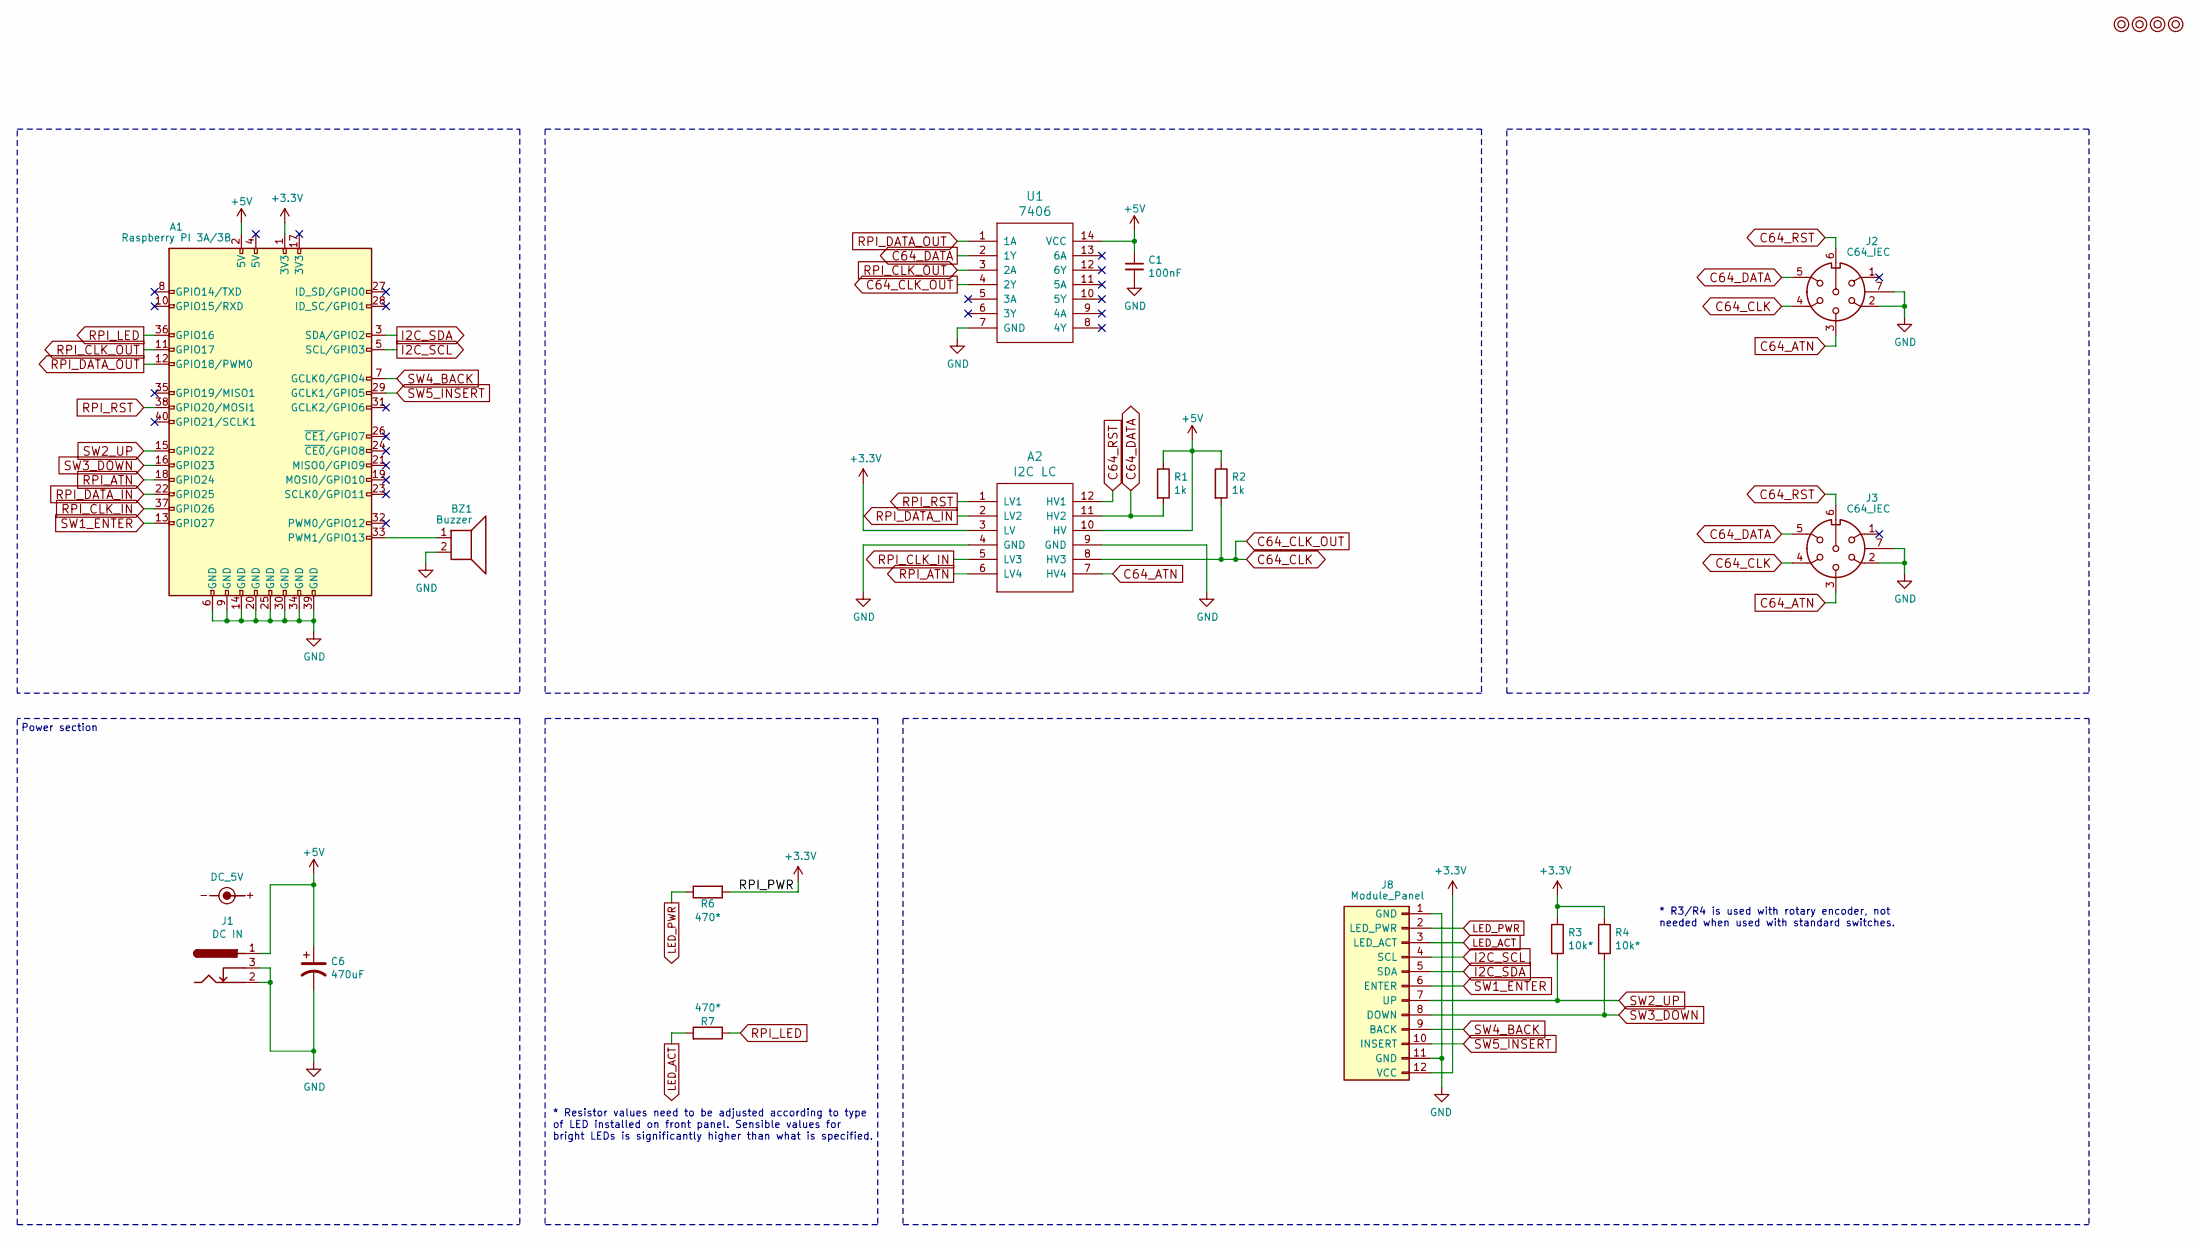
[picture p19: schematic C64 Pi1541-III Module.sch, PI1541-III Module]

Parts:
A1: Raspberry PI 3A/3B; Raspberry_Pi_3B_Socketed_THT_FaceDown_MountingHoles
A2: I2C LC; 4CH_I2C_Level_Converter
BZ1: Buzzer; Buzzer_12x9.5RM7.6
C1: 100nF; C_Disc_D4.7mm_W2.5mm_P5.00mm
C6: 470uF; CP_Radial_D8.0mm_P3.50mm
J1: DC IN; BARREL_JACK
J2, J3: C64_IEC; DIN6_IEC
J8: Module_Panel
M1, M2, M3, M4: Mounting; M3
R1, R2: 1k; R_Axial_DIN0207_L6.3mm_D2.5mm_P10.16mm_Horizontal
R3, R4: 10k*; R_Axial_DIN0207_L6.3mm_D2.5mm_P10.16mm_Horizontal
R6, R7: 470*; R_Axial_DIN0207_L6.3mm_D2.5mm_P10.16mm_Horizontal
SYM1: DC_5V; PWR_Specification
U1: 7406; DIP-14_W7.62mm_Socket_LongPads

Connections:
+3V3: A1.1 (3V3), A2.3 (LV), J8.12 (VCC), R3.1, R4.1, R6.2
+5V: A1.2 (5V), A2.10 (HV), C1.1, C6.1, J1.1, R1.1, R2.1, U1.14 (VCC)
C64_ATN: A2.7 (HV4), J2.3, J3.3
C64_CLK: A2.8 (HV3), J2.4, J3.4, R2.2, U1.4 (2Y)
C64_DATA: A2.11 (HV2), J2.5, J3.5, R1.2, U1.2 (1Y)
C64_RST: A2.12 (HV1), J2.6, J3.6
GND: A1.6 (GND), A1.9 (GND), A1.14 (GND), A1.20 (GND), A1.25 (GND), A1.30 (GND), A1.34 (GND), A1.39 (GND), A2.4 (GND), A2.9 (GND), BZ1.2, C1.2, C6.2, J1.2, J1.3, J2.2, J2.7, J3.2, J3.7, J8.1 (GND), J8.11 (GND), U1.7 (GND)
I2C_SCL: A1.5 (SCL/GPIO3), J8.4 (SCL)
I2C_SDA: A1.3 (SDA/GPIO2), J8.5 (SDA)
LED_ACT: J8.3 (LED_ACT), R7.2
LED_PWR: J8.2 (LED_PWR), R6.1
unnamed: A1.33 (PWM1/GPIO13), BZ1.1
RPI_ATN: A1.18 (GPIO24), A2.6 (LV4)
RPI_CLK_IN: A1.37 (GPIO26), A2.5 (LV3)
RPI_CLK_OUT: A1.11 (GPIO17), U1.3 (2A)
RPI_DATA_IN: A1.22 (GPIO25), A2.2 (LV2)
RPI_DATA_OUT: A1.12 (GPIO18/PWM0), U1.1 (1A)
RPI_LED: A1.36 (GPIO16), R7.1
RPI_RST: A1.38 (GPIO20/MOSI1), A2.1 (LV1)
SW1_ENTER: A1.13 (GPIO27), J8.6 (ENTER)
SW2_UP: A1.15 (GPIO22), J8.7 (UP), R3.2
SW3_DOWN: A1.16 (GPIO23), J8.8 (DOWN), R4.2
SW4_BACK: A1.7 (GCLK0/GPIO4), J8.9 (BACK)
SW5_INSERT: A1.29 (GCLK1/GPIO5), J8.10 (INSERT)

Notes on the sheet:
Power section
* R3/R4 is used with rotary encoder, not needed when used with standard switches.
* Resistor values need to be adjusted according to type of LED installed on front panel. Sensible values for bright LEDs is significantly higher than what is specified.

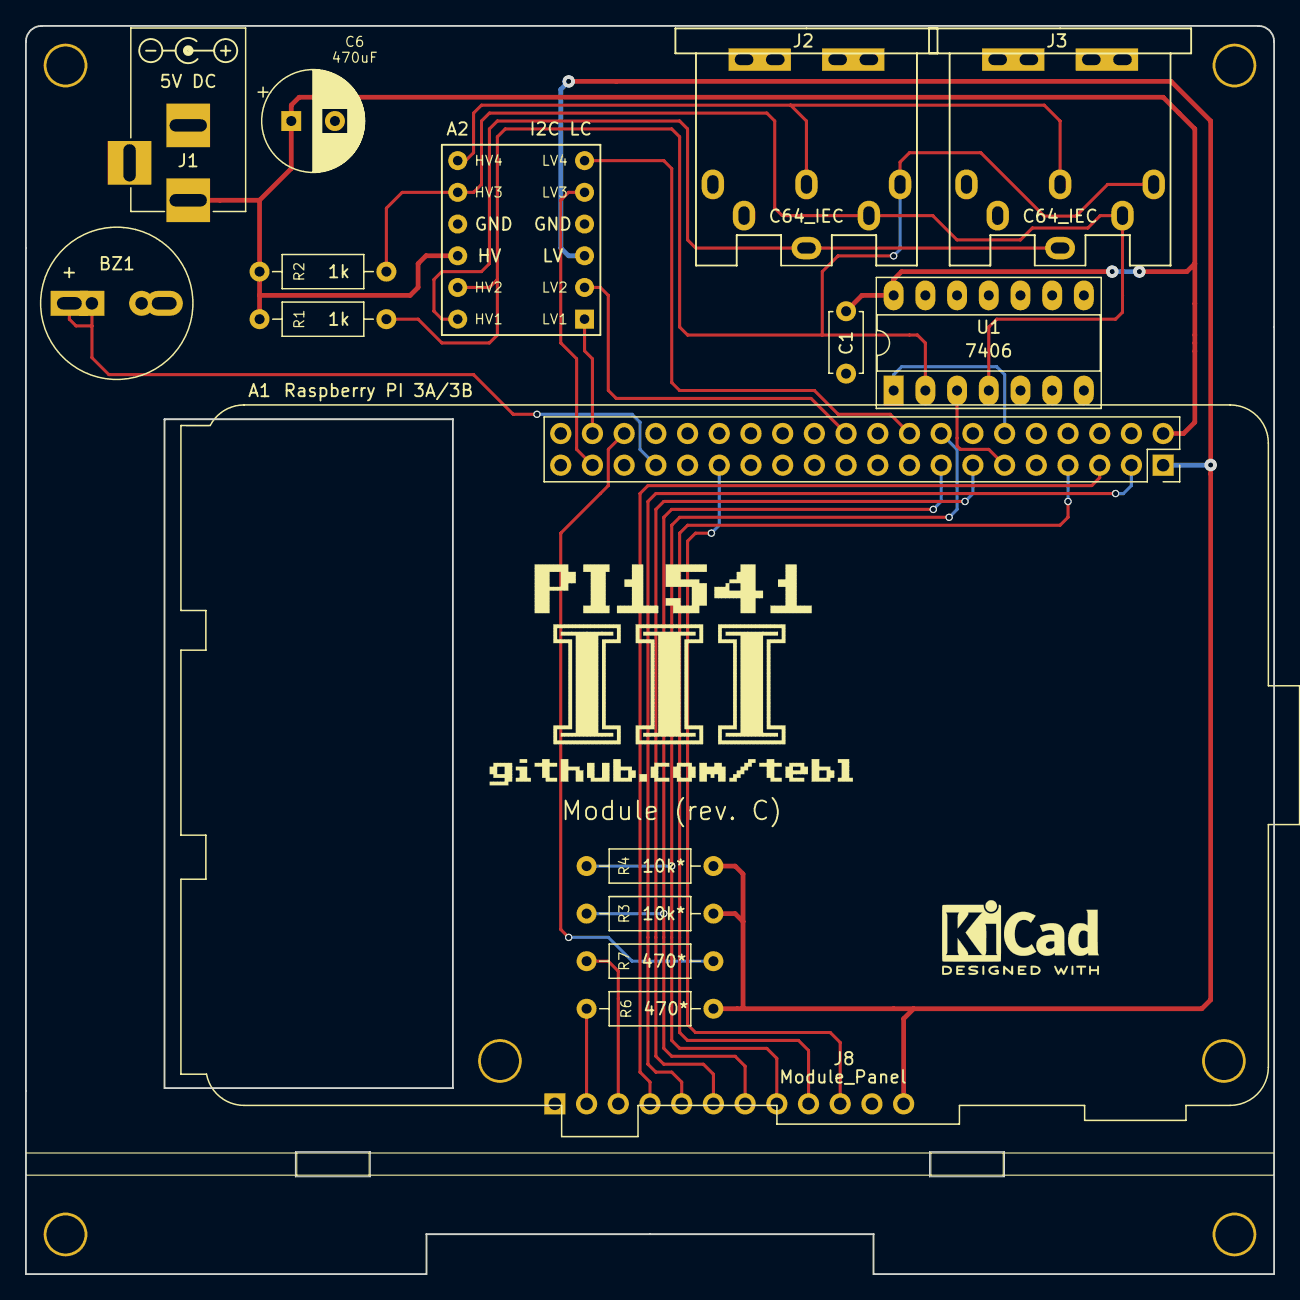
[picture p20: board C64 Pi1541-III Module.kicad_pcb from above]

Board: 2 copper layers, 100.0 x 100.0 mm, 22 parts (1 on the bottom side), 24 nets.

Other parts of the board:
Pi1541-drive: Pi1541-drive

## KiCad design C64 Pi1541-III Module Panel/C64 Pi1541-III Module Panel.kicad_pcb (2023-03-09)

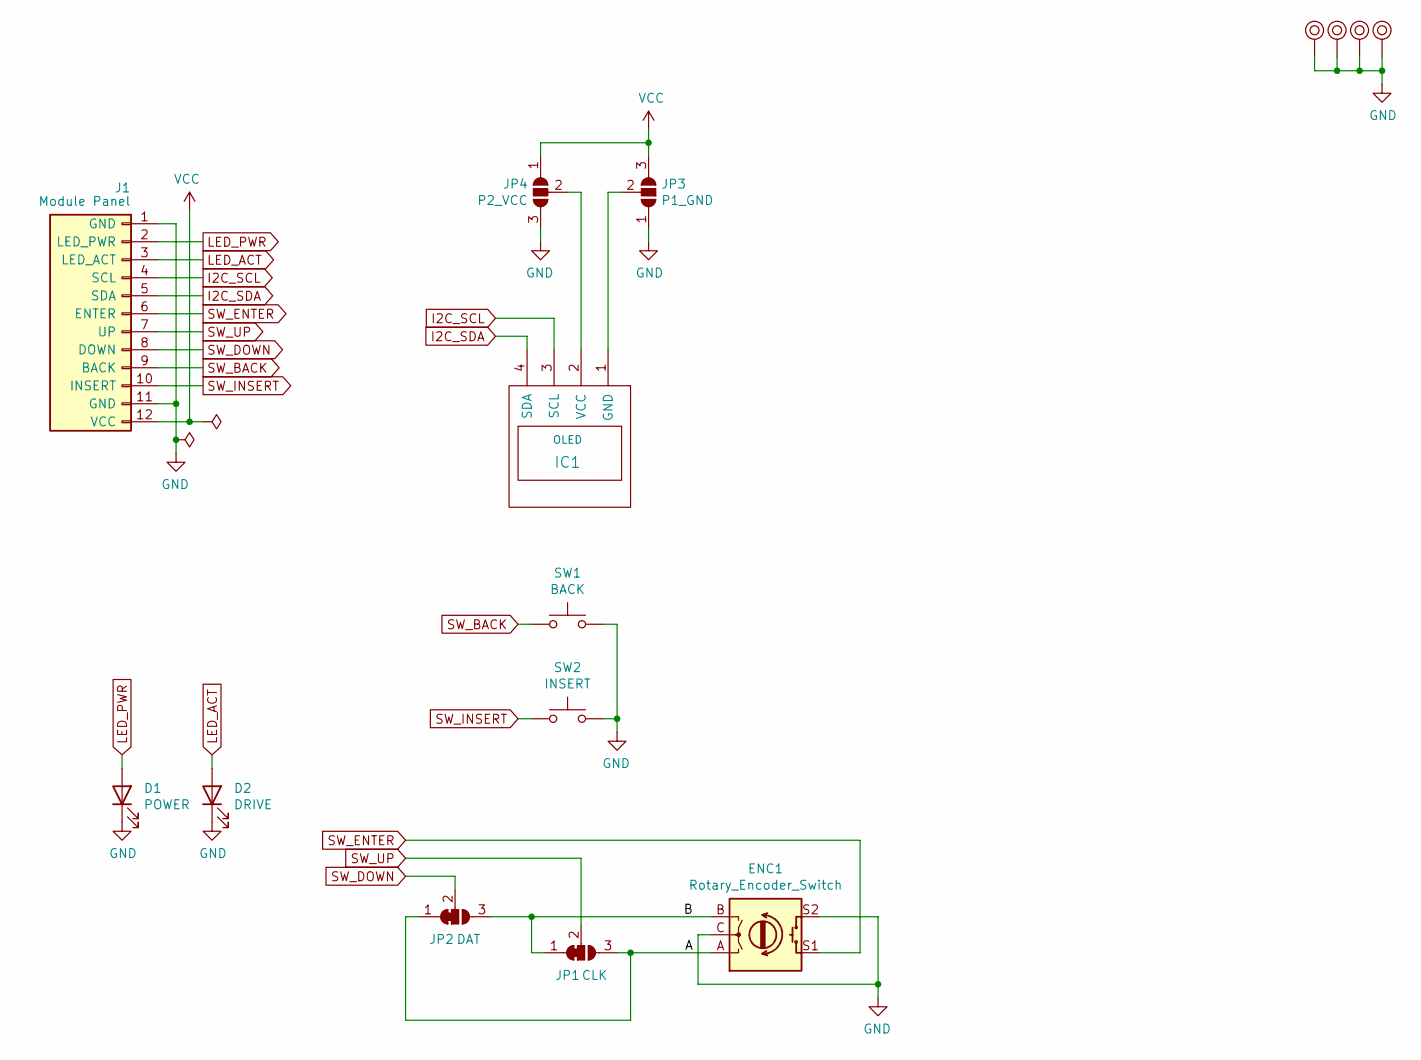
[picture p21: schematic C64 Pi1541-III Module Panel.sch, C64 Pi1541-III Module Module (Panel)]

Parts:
D1: POWER; LED_Rectangular_W3.0mm_H2.0mm
D2: DRIVE; LED_Rectangular_W3.0mm_H2.0mm
ENC1: Rotary_Encoder_Switch; RotaryEncoder_Alps_EC11E-Switch_Vertical_H20mm
IC1: OLED; 1.3_I2C_OLED_No_mounting
J1: Module Panel; PinHeader_1x12_P2.54mm_Horizontal
JP1: CLK; SolderJumper-3_P1.3mm_Open_Pad1.0x1.5mm
JP2: DAT; SolderJumper-3_P1.3mm_Open_Pad1.0x1.5mm
JP3: P1_GND; SolderJumper-3_P1.3mm_Open_Pad1.0x1.5mm
JP4: P2_VCC; SolderJumper-3_P1.3mm_Open_Pad1.0x1.5mm
M1, M2, M3, M4: Mounting_Pin; M3_pin
SW1: BACK; SW_PUSH_6mm
SW2: INSERT; SW_PUSH_6mm

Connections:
/A: ENC1.A, JP1.3 (B), JP2.1 (A)
/B: ENC1.B, JP1.1 (A), JP2.3 (B)
GND: D1.1 (K), D2.1 (K), ENC1.C, ENC1.S2, J1.1 (GND), J1.11 (GND), JP3.1 (A), JP4.3 (B), M1.1, M2.1, M3.1, M4.1, SW1.2, SW2.2
I2C_SCL: IC1.3 (SCL), J1.4 (SCL)
I2C_SDA: IC1.4 (SDA), J1.5 (SDA)
LED_ACT: D2.2 (A), J1.3 (LED_ACT)
LED_PWR: D1.2 (A), J1.2 (LED_PWR)
unnamed: IC1.1 (GND), JP3.2 (C)
unnamed: IC1.2 (VCC), JP4.2 (C)
SW_BACK: J1.9 (BACK), SW1.1
SW_DOWN: J1.8 (DOWN), JP2.2 (C)
SW_ENTER: ENC1.S1, J1.6 (ENTER)
SW_INSERT: J1.10 (INSERT), SW2.1
SW_UP: J1.7 (UP), JP1.2 (C)
VCC: J1.12 (VCC), JP3.3 (B), JP4.1 (A)

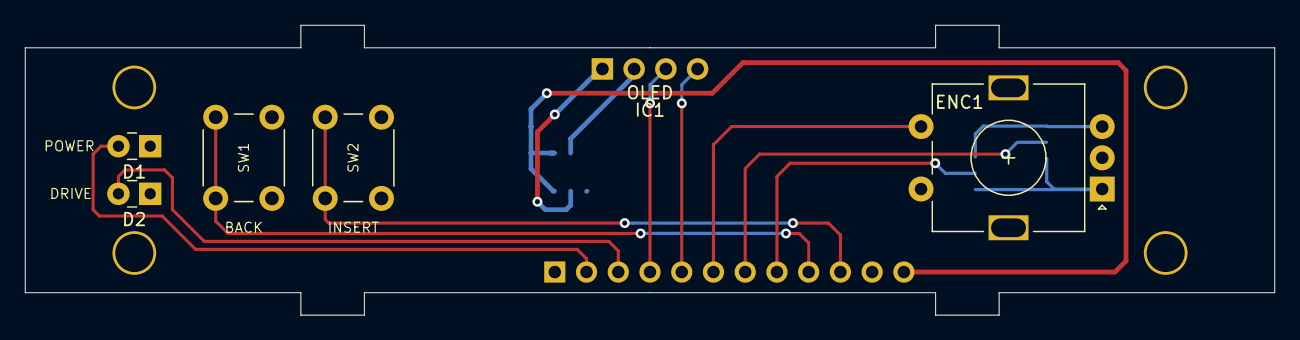
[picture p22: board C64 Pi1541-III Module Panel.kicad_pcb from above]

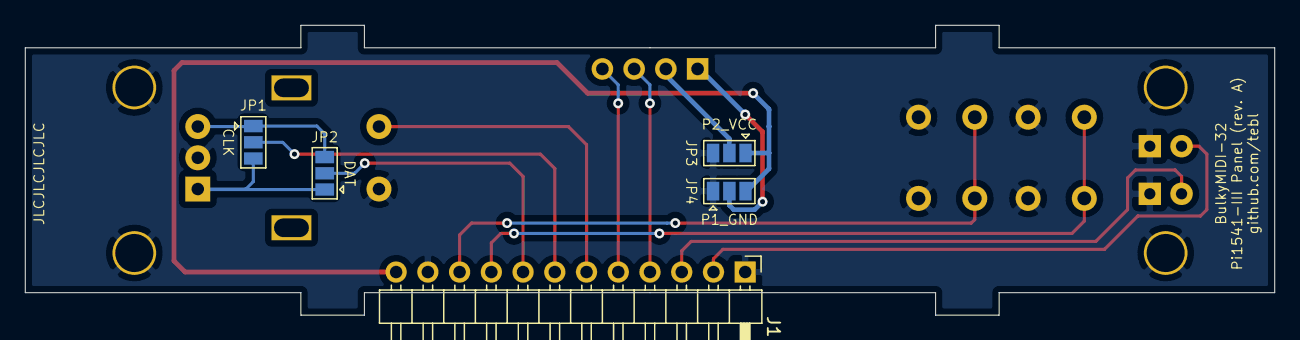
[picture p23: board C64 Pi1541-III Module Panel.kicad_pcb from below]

Board: 2 copper layers, 100.0 x 23.2 mm, 15 parts (5 on the bottom side), 15 nets.

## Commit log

2023-03-08 Main module added
    [C64 Pi1541-III Module.kicad_pcb, C64 Pi1541-III Module.sch]
2023-03-09 First layout done
    [C64 Pi1541-III Module FB1.kicad_pcb, C64 Pi1541-III Module FB1.sch, C64 Pi1541-III Module FP1.kicad_pcb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]
2023-03-23 Fix DIN-footprint
    [C64 Pi1541-III Module.kicad_pcb]
2023-03-23 Adjust cutout for LEDs slightly
    [C64 Pi1541-III Module FP1.kicad_pcb]
2023-03-23 Tweak footprint placement
    [C64 Pi1541-III Module FB1.kicad_pcb]
2023-03-23 Lock footprint
    [C64 Pi1541-III Module FB1.kicad_pcb]
2023-03-23 Changed decal wording
    [C64 Pi1541-III Module FB1.kicad_pcb, C64 Pi1541-III Module FP1.kicad_pcb]
2023-03-23 Added bottom plate design
    [C64 Pi1541-III Module FB2.kicad_pcb, C64 Pi1541-III Module FB2.sch]
2023-03-23 Adjust LED resistor value
    [C64 Pi1541-III Module.kicad_pcb, C64 Pi1541-III Module.sch]
2023-03-26 Exported files
    [C64 Pi1541-III Module FB1.kicad_pcb, C64 Pi1541-III Module FB2.kicad_pcb, C64 Pi1541-III Module.kicad_pcb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]
2023-04-04 Moved components around to make it easier to build
    [C64 Pi1541-III Module.kicad_pcb, C64 Pi1541-III Module.sch]
